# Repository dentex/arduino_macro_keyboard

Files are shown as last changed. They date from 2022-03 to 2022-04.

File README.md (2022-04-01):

# Arduino Macro Keyboard

DIY *Macro Keyboard* using an Arduino Pro Micro, 3D printed parts and some other hardware modules.

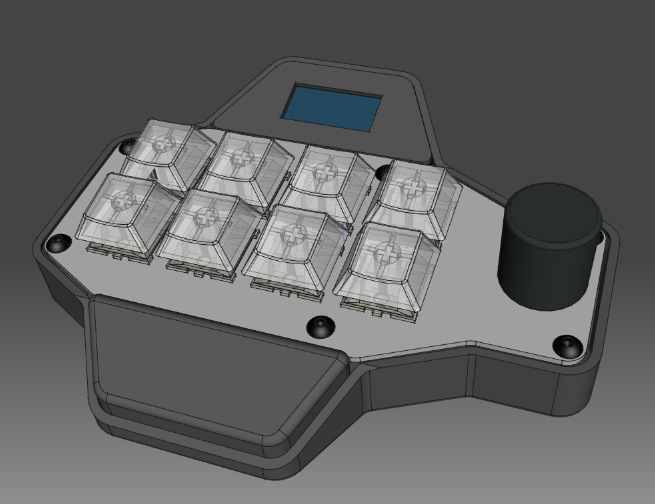
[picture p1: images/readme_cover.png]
cover image


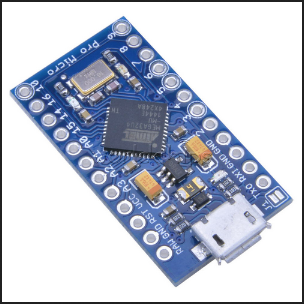
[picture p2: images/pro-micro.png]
pro-micro


## Features

- Arduino Pro Micro as HID device
- 8 configurable keyboard switches and 1 rotary encoder
- Independent profiles for keys and encoder
- Touch sensor to detect interaction
- A ws2812b LED module lights-up the pad upon profile changes and when the touch sensor is touched
- OLED display to show usage info
- Menu Button (placed below the OLED display) with key-test playground

## Arduino sketch

Find it at [./sketch/pro-micro_dentex_macro-keyboard.ino](/sketch/pro-micro_dentex_macro-keyboard.ino).

Libraries used:
- HID-Project
- EEPROM
- Adafruit_NeoPixel
- SSD1306Ascii
- Keypad

## 3D printed parts

Printable STL files are available in the [relative folder](/STL). The [./FreeCAD](/FreeCAD) folder contains the 3D project (the main file to be loaded in FreeCAD is `#_MACRO-KEYBOARD_v12.FCStd`)

## Hardware

- 1 Arduino Pro Micro
- 8 Cherry MX switches (or similar/compatible, i.e.: https://www.aliexpress.com/item/4001111706889.html)
- 8 Keycaps (4xR1 and 4xR2: https://www.aliexpress.com/item/33056163268.html)
- 1 Rotary Encoder (I used a KY_040 module, it should be this one: https://www.aliexpress.com/item/32726570531.html)
- 6 short M3 hexagonal screws
- 6 M3X4.6X4.0 Brass Insert Nuts (i.e.: https://www.aliexpress.com/item/4000688990203.html)
- 1 6x6x5mm tactile mini switch (i.e.: https://www.aliexpress.com/item/1005003536610720.html)
- 1 3mm LED (indicates the encoder's ticking)
- 1 Addressable LED module (i.e.: https://www.aliexpress.com/item/32851699524.html)
- 1 I2C OLED Display Module (i.e.: https://fr.aliexpress.com/item/32584349265.html type 0.96 white)
- 1 TTP223 Capacitive Touch Switch Module(i.e.: https://www.aliexpress.com/item/32869836574.html)

## Wiring

A partial connection diagram is present into the [./images](/images) folder. It covers the keyboard and the rotary encoder. For the other connections, rely on the Arduino sketch and the [arduino pinout](/images/pro-micro-pinout.jpg).

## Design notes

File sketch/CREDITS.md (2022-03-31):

# 1

*T H E   K N O B*
*Media Controller Mk III*

By Frank Lumien: www.lumien.se
Arduino code by: IAmOrion aka James Tanner

Version 2.0

FUNCTIONS
Turn knob left: Volume down
Turn knob right: Volume up
Press knob: Play & Pause (alternating)
Press and turn knob left: Previous track
Press and turn knob right: Next track

Note: You can change all of these functions, see Settings.h for more.

PINOUT, pro-micro to KY-040
D14   to  CLK
D15   to  DT
D16   to  SW
VIN  to  GND // reversed
GND  to  +5V // reversed
Note: The position of these pins may depend on your board and encoder.
If you have already soldered or if The Knob doesn’t behave as expected,
you can adjust the pin settings in Settings.h

# 2

**TinyMultimediaController**
*Multimedia controller using a Digispark*
*(ATtiny85) and a rotary encoder*

Copyright (C) 2018 Costin STROIE <costinstroie@eridu.eu.org>

This program is free software: you can redistribute it and/or modify
it under the terms of the GNU General Public License as published by
the Free Software Foundation, either version 3 of the License, or
(at your option) any later version.

This program is distributed in the hope that it will be useful,
but WITHOUT ANY WARRANTY; without even the implied warranty of
MERCHANTABILITY or FITNESS FOR A PARTICULAR PURPOSE.  See the
GNU General Public License for more details.

You should have received a copy of the GNU General Public License
along with this program.  If not, see <http://www.gnu.org/licenses/>.

# 3

`TODO`

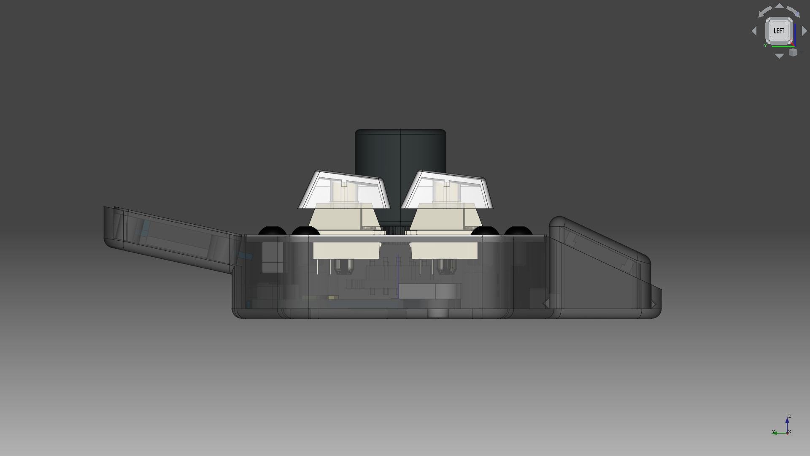
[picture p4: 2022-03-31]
images/o6.png

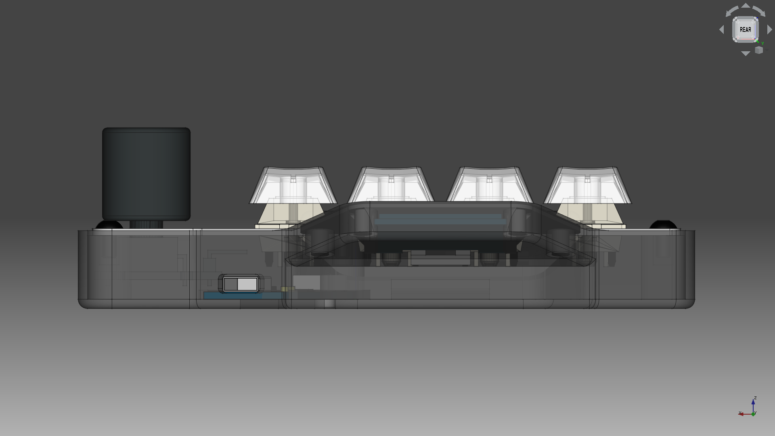
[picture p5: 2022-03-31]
images/o4.png

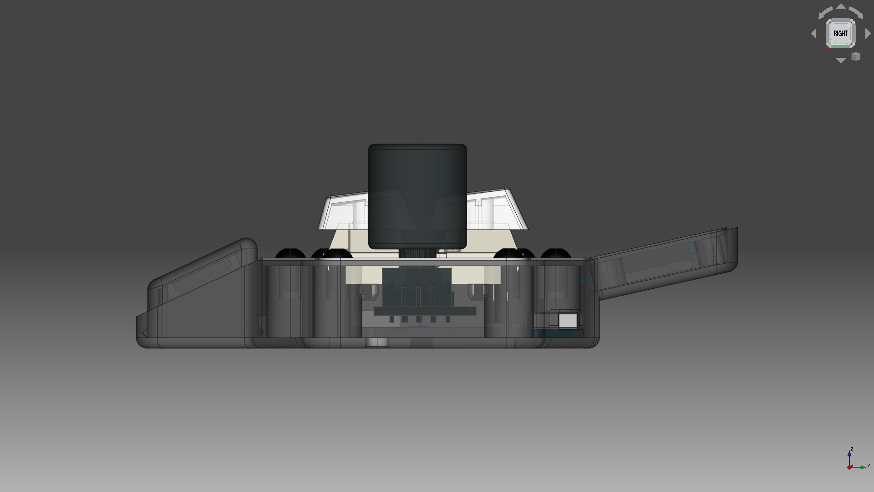
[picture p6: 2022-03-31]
images/o3.png

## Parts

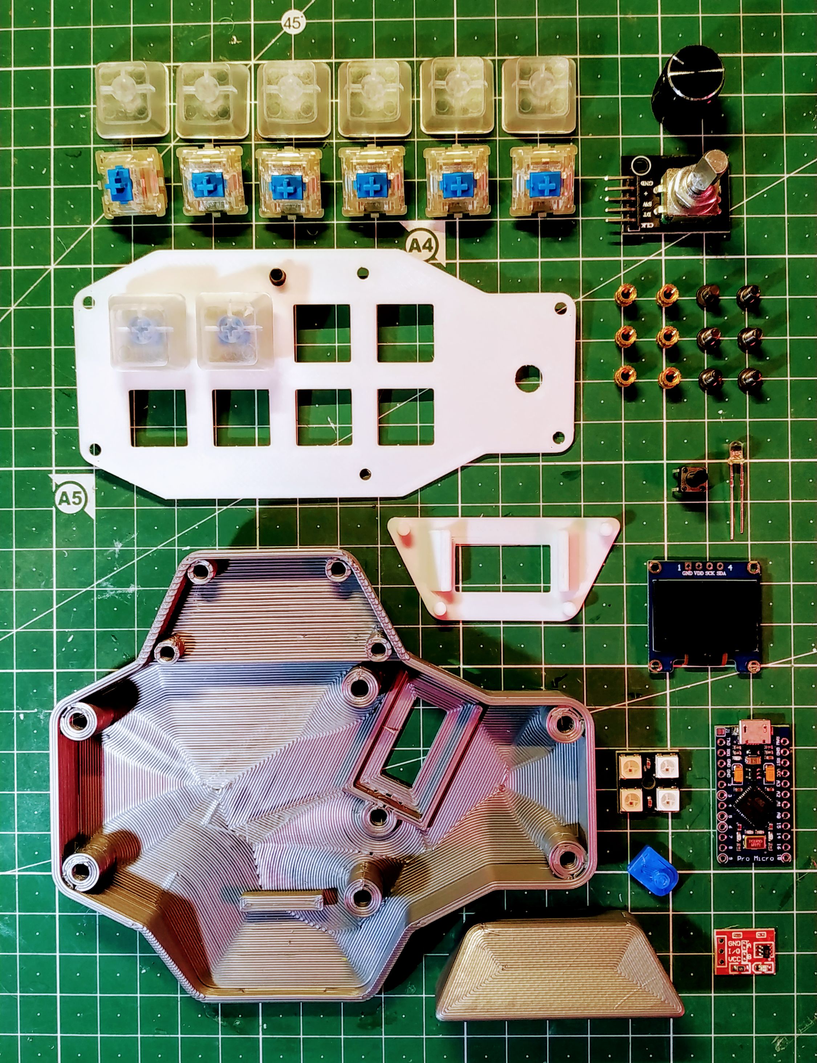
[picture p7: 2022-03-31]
images/IMG_20210107_parts.jpg

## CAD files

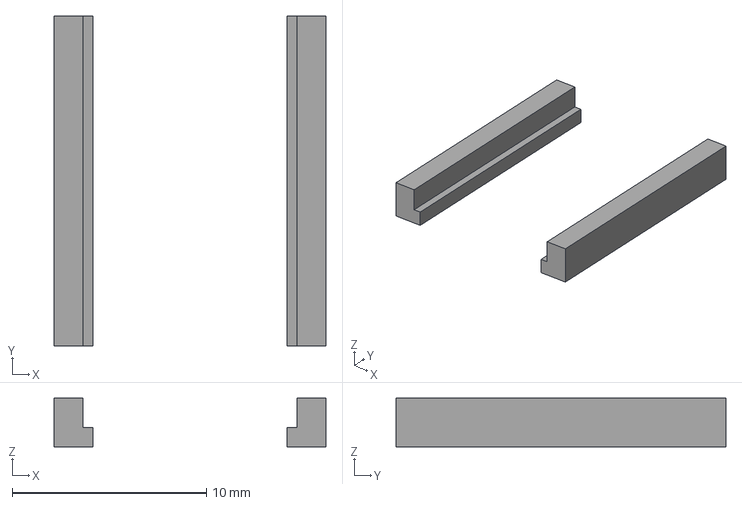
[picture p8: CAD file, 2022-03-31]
FreeCAD/ts-sled.FCStd
14.0 x 17.0 x 2.50 mm
Cut_TS_sled

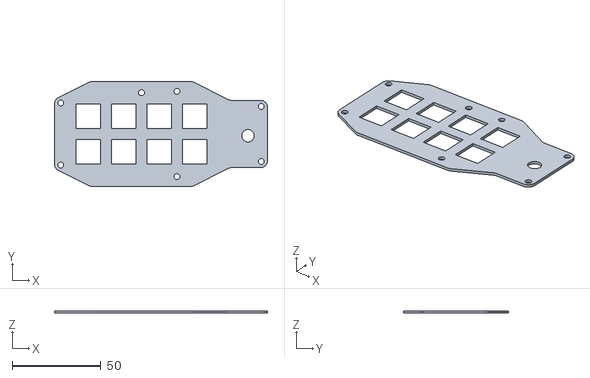
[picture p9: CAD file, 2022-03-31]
STL/cmx_frame_v8.stl
120.0 x 59.0 x 1.40

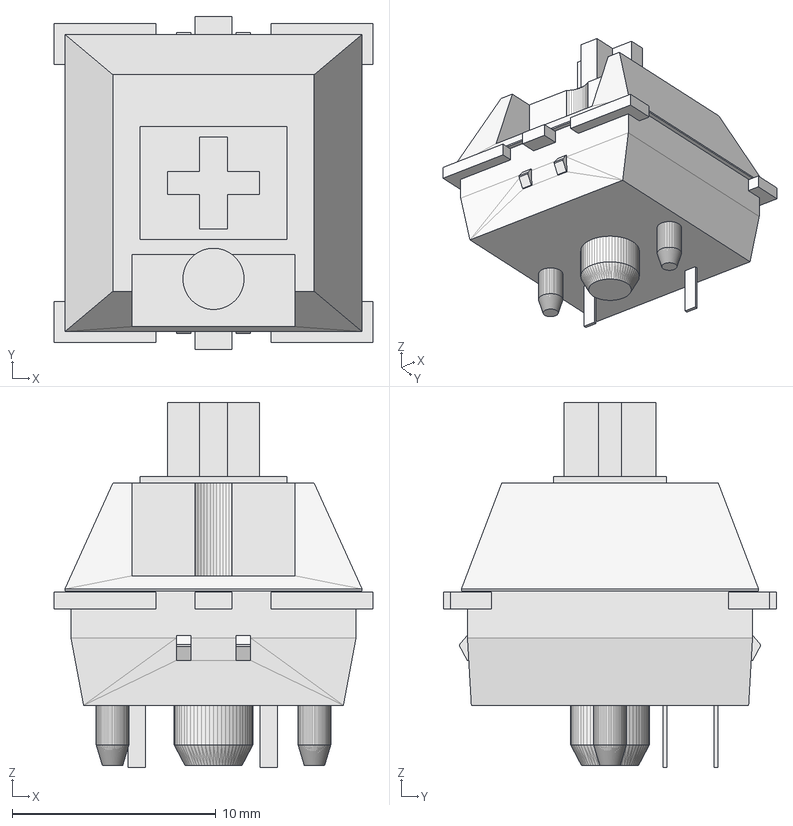
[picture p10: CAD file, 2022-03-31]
FreeCAD/cmx.FCStd
15.6 x 16.3 x 17.9 mm

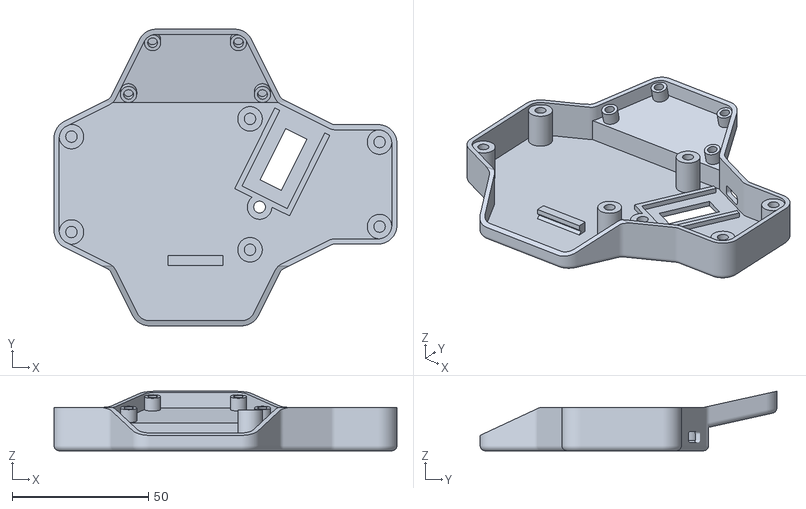
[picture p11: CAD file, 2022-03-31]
STL/base_v10.stl
125.8 x 108.8 x 21.9

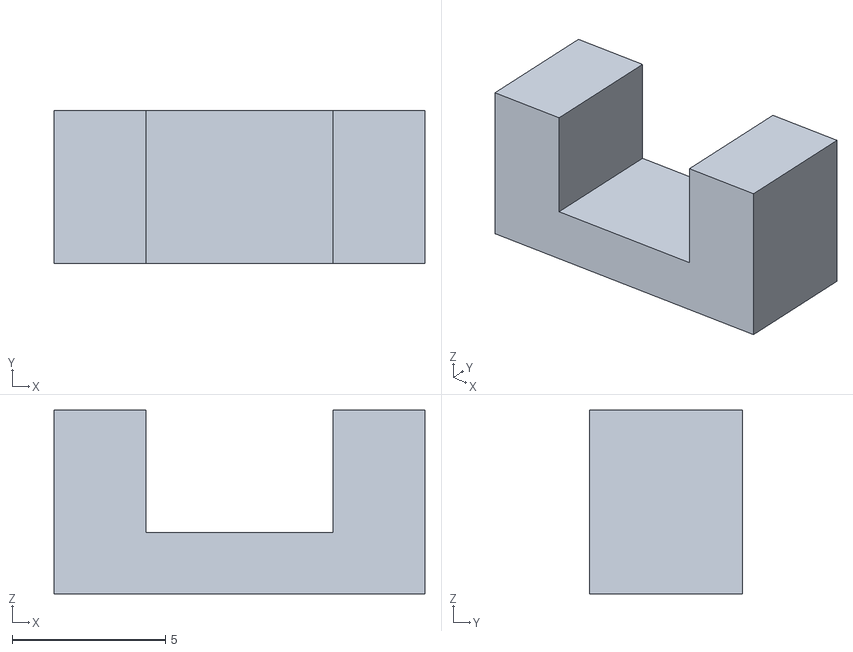
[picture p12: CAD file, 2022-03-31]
STL/mb_supp_v8.stl
12.1 x 5.00 x 6.00

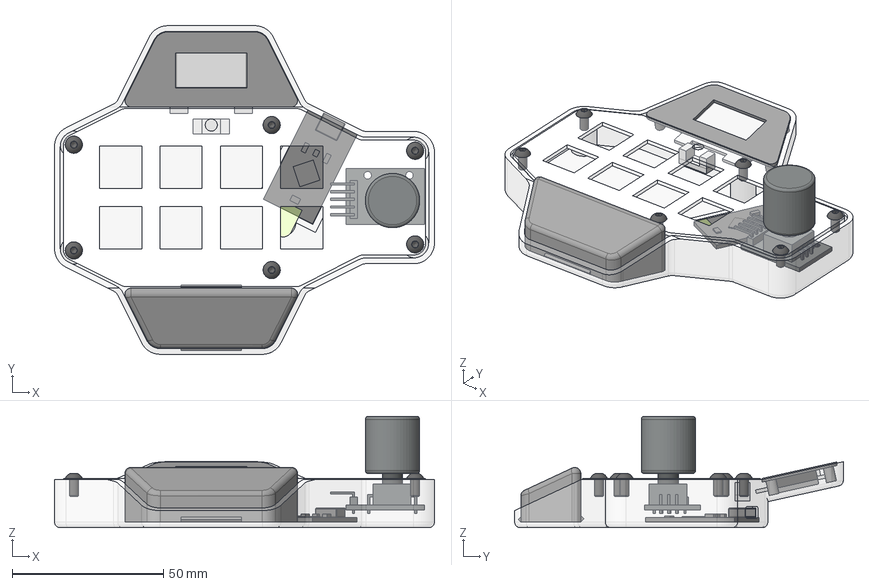
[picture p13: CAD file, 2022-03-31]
FreeCAD/#_MACRO-KEYBOARD_v12.FCStd
125.8 x 108.8 x 36.9 mm
standoffs
Frame_FINAL_[A]
Body_BASE_002
Body_OLED_frame_002
menu_butt_supp
pro-micro_blocker
pro-micro
Body_OLED
encoder+knob
palm-rest_FINAL
M3x6-Screw
M3x6-Screw001
M3x6-Screw002
M3x6-Screw003
M3x6-Screw004
M3x6-Screw005

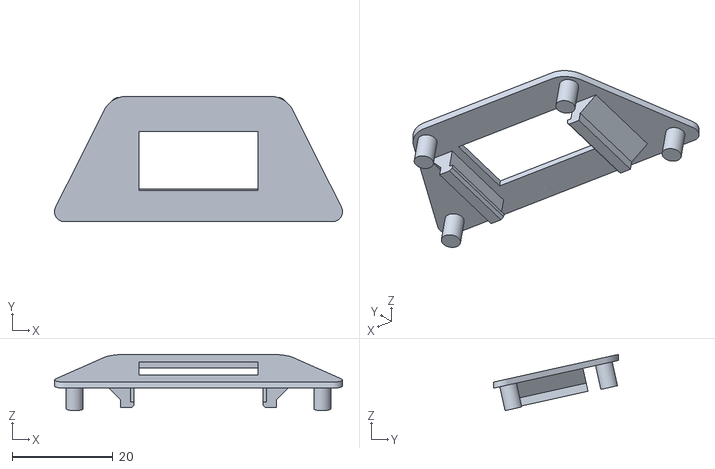
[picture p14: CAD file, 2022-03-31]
STL/OLED_frame_v8.stl
57.1 x 24.8 x 11.2

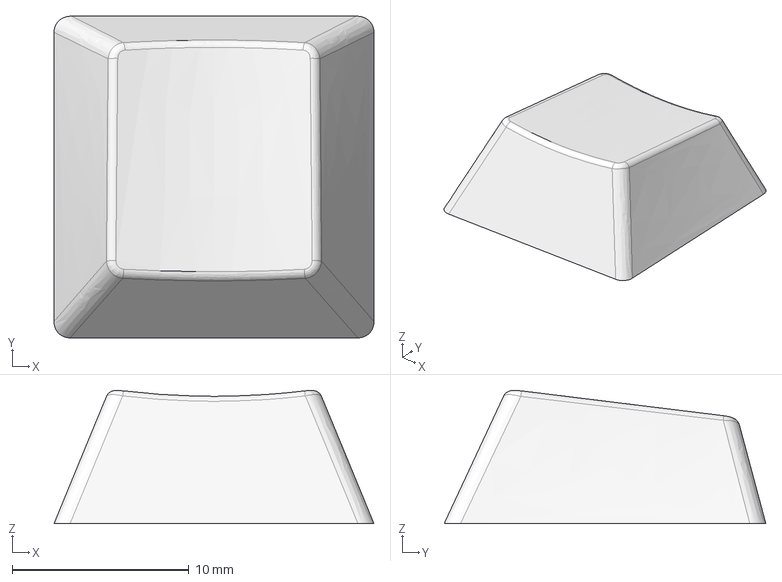
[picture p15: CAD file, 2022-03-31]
FreeCAD/keycap.FCStd
18.1 x 18.2 x 7.54 mm

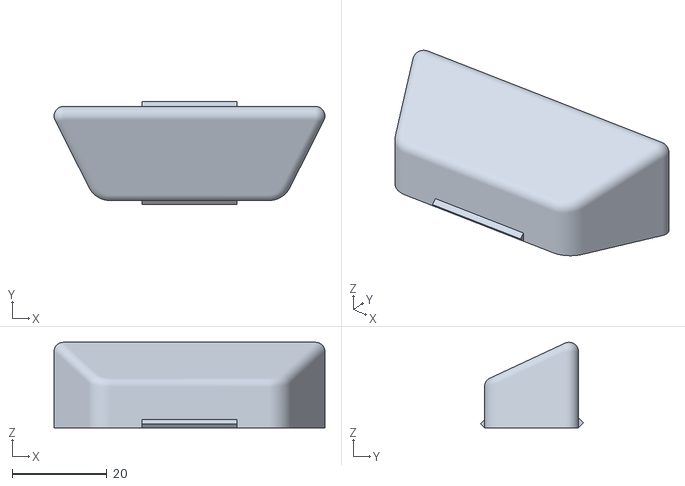
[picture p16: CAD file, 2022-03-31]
STL/palm-rest_v9.stl
57.2 x 21.8 x 18.1

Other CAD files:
FreeCAD/cmx+keycap.FCStd

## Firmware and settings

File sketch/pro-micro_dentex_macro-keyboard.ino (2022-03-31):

/* 
 * Ultimate Macro Keyboard
 * 
 * Copyright (C) 2020 Samuele Rini <samuele.rini76 [AT] gmail.com>
 *
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
 * You should have received a copy of the GNU General Public License
 * along with this program.  If not, see <http://www.gnu.org/licenses/>.
 */

/* 
 * ----------------------------------------
 * Realized adapting and modifing code from 
 * the projects specified under CREDITS.md
 * ----------------------------------------
*/

#include <Arduino.h>

#include "Settings.h"

// #include <EEPROMWearLevel.h>
#include <EEPROM.h>

#include <Adafruit_NeoPixel.h>
Adafruit_NeoPixel strip = Adafruit_NeoPixel(LEDS_NUM, DIN_PIN, NEO_GRB + NEO_KHZ800);

#include "SSD1306Ascii.h"
#include "SSD1306AsciiWire.h"
SSD1306AsciiWire oled;

#include "DeadSimpleMenu.h"
DeadSimpleMenu dsm;

#include <Keypad.h>

byte rowPins[ROWS] = {15, 14};     //connect to the row pinouts of the keypad
byte colPins[COLS] = {4, 5, 6, 7}; //connect to the column pinouts of the keypad

Keypad keypad = Keypad(makeKeymap(keys), rowPins, colPins, ROWS, COLS);

int encButtonState = LOW, lastEncButtonState = LOW;
int menuButtonState = LOW, lastMenuButtonState = LOW;
int touchSensorState = LOW, lastTouchSensorState = LOW;

unsigned long lastDebounceTime = 0, debounceDelay = 50;
int _position = 0, _positionExt = 0;
int8_t _oldState;
bool btnPressed = false, btnReleased = false, pressedRotary = false;

const int8_t encoderStates[] = {
    0, -1, 1, 0,
    1, 0, 0, -1,
    -1, 0, 0, 1,
    0, 1, -1, 0};

//Functions prototypes (due to the optional parameter)
//********************************************************************************
void oledOn(const char *msg, bool isIgnoring = false);
void drawMenu(int page = INITIAL_PAGE);
//void keySend(KeyboardKeycode key, bool useCtrl = false, bool useShift = false);
//********************************************************************************

void colorWipe(uint32_t c, uint8_t wait)
{
    for (uint16_t i = 0; i < strip.numPixels(); i++)
    {
        strip.setPixelColor(i, c);
        strip.show();
        delay(wait);
    }
}

void stripSetColor(uint8_t encP = -1, uint8_t keyP = -1)
{
    uint8_t wait = 100;

    switch (keyP)
    {
    case OLIVE_KP:
        colorWipe(strip.Color(0, 255, 0), wait); // Green
        break;
    case NAV_KP:
        colorWipe(strip.Color(255, 0, 0), wait); // Red
        break;
    default:
        switch (encP)
        {
        case MMEDIA_ENC:
            switch (keyP)
            {
            case APPS_KP:
                colorWipe(strip.Color(0, 0, 255), wait); // Blue
                break;
            case KRITA_KP:
                colorWipe(strip.Color(127, 0, 255), wait); // Purple/Blue
                break;
            }
            break;
        case KRITA_ENC:
            switch (keyP)
            {
            case APPS_KP:
                colorWipe(strip.Color(255, 255, 0), wait); // Yellow
                break;
            case KRITA_KP:
                colorWipe(strip.Color(255, 0, 127), wait); // Purple/Red
                break;
            }
            break;
        default:
            colorWipe(strip.Color(0, 0, 0), wait); // Black
            break;
        }
    }
}

/*
// colors 
colorWipe(strip.Color(255, 0, 0), wait); // Red
colorWipe(strip.Color(0, 255, 0), wait); // Green
colorWipe(strip.Color(0, 0, 255), wait); // Blue
colorWipe(strip.Color(0, 0, 0), wait); // Black 
*/

bool menuMode = false;
bool showcaseMode = false;

int storedEncoderProfile;
int currentEncoderProfile;
int encoderProfile;

int storedKeypadProfile;
int currentKeypadProfile;
int keypadProfile;

void quitMenu()
{
    //Serial.print("\n Exting Menu");
    menuMode = false;
    showcaseMode = false;
    exitMenu();
}

void assignEncoderProfile(int encoderProfile)
{
    //Serial.print("\n Assigning encoder profile ");
    //Serial.print(encoderProfile);
    currentEncoderProfile = encoderProfile;

    EEPROM.update(ENCODER_PROFILE_SETTING, encoderProfile);

    stripSetColor(encoderProfile, currentKeypadProfile);
    stripSetColor();
}

void assignKeypadProfile(int keypadProfile)
{
    //Serial.print("\n Assigning keypad profile ");
    //Serial.print(keypadProfile);
    currentKeypadProfile = keypadProfile;

    EEPROM.update(KEYPAD_PROFILE_SETTING, keypadProfile);

    stripSetColor(currentEncoderProfile, keypadProfile);
    stripSetColor();
}

void setup()
{
    pinMode(encoderPinA, INPUT);
    pinMode(encoderPinB, INPUT);
    pinMode(encoderButton, INPUT);

    digitalWrite(encoderButton, LOW);
    _oldState = 3;

    pinMode(TOUCH_SENSOR, INPUT);

    pinMode(MENU_BUTTON, INPUT);
    digitalWrite(MENU_BUTTON, LOW);

    //Serial.begin(9600 * 2);
    //EEPROMwl.begin(EEPROM_LAYOUT_VERSION, AMOUNT_OF_INDEXES);

    // uncomment to wait for serial connection before continuing
    /* while (!Serial)
    {
        ;
    } */

    storedEncoderProfile = EEPROM.read(ENCODER_PROFILE_SETTING);

    currentEncoderProfile = storedEncoderProfile;
    encoderProfile = storedEncoderProfile;

    storedKeypadProfile = EEPROM.read(KEYPAD_PROFILE_SETTING);

    currentKeypadProfile = storedKeypadProfile;
    keypadProfile = storedKeypadProfile;

    Wire.begin();
    oled.begin(&Adafruit128x64, I2C_ADDRESS);
    oled.setFont(menuFont);

    oledOn(" Macro-Keyboard\n   by Dentex");
    delay(STANDARD_MS);

    oled.clear();

    dsm.attachOled(oled);

    pinMode(TICK_LED, OUTPUT);
    ledOn();
    ledTimeout += ledDelay;

    strip.begin();
    strip.setBrightness(BRIGHTNESS);

    stripSetColor(currentEncoderProfile, currentKeypadProfile);
    stripSetColor();

#ifndef ENCODER_DEBUG
    {
        Consumer.begin();
    }
#endif

    Keyboard.begin();
}

void keySend(KeyboardKeycode key, bool useCtrl = false, bool useShift = false /*, bool useAlt = false */)
{
    if (!menuMode)
    {
        // Turn the LED on
        ledOn();

        // Send the key
        if (useCtrl)
        {
            Keyboard.press(KEY_LEFT_CTRL);
        }
        if (useShift)
        {
            Keyboard.press(KEY_LEFT_SHIFT);
        }
        /* if (useAlt)
        {
            Keyboard.press(KEY_LEFT_ALT);
        } */
        Keyboard.press(key);
        delay(5);
        Keyboard.releaseAll();
    }
}

void consumerSend(ConsumerKeycode key)
{
    ledOn();
    Consumer.write(key);
}

/*
  Turn the LED on and set the timeout
*/
void ledOn()
{
    if (!ledLight)
    {
        ledLight = true;
        digitalWrite(TICK_LED, HIGH);
    }
    ledTimeout = millis() + ledDelay;
}

void oledOn(const char *msg, bool isIgnoring)
{
    const char *oldMsg = "";
    if (!menuMode || isIgnoring)
    {
        if (!oledLight || msg != oldMsg)
        {
            oledLight = true;
            oled.clear();
            oled.setCursor(0, 0);
            oled.println(msg);
            oldMsg = msg;
        }
        oledTimeout = millis() + oledDelay;
    }

    if (showcaseMode)
    {
        oled.setCursor(0, 3);
        oled.println(msg);
        oldMsg = msg;
    }
}

/*
  Check the timeout and turn the LED off

  @param nowMillis cached millis()
*/
void ledOff(unsigned long nowMillis)
{
    if (ledLight and (nowMillis > ledTimeout))
    {
        ledLight = false;
        digitalWrite(TICK_LED, LOW);
    }
}

void oledOff(unsigned long nowMillis)
{
    if (oledLight and (nowMillis > oledTimeout) && !menuMode)
    {
        oledLight = false;
        oled.clear();
    }
}

int getPosition()
{
    return _positionExt;
}

/* void setPosition(int newPosition)
{
    _position = ((newPosition << 2) | (_position & 0x03));
    _positionExt = newPosition;
} */

void tick(void)
{
    int sig1 = digitalRead(encoderPinA);
    int sig2 = digitalRead(encoderPinB);
    int8_t thisState = sig1 | (sig2 << 1);
    if (_oldState != thisState)
    {
        _position += encoderStates[thisState | (_oldState << 2)];
         if ((thisState == 0) || (thisState == 3))
            _positionExt = _position >> 2;
        _oldState = thisState;
    }
}

void exitMenu()
{
    oledOn("EXIT\n Menu");
}

void drawMenu(int page)
{
    oled.clear();
    dsm.menuPage = page;

    switch (page)
    {
    case INITIAL_PAGE: // initial menu page
        dsm.currentLine = 0;
        dsm.maxLinesNum = 3;
        dsm.setLine(0, menuLineEnc + EncProfileNames[currentEncoderProfile]);
        dsm.setLine(1, menuLineKp + KpProfileNames[currentKeypadProfile]);
        dsm.setLine(2, menuLineTest);
        dsm.setLine(3, menuLineBack);
        break;

    case ENC_PROFILE_PAGE: // choose Encoder profile page
        dsm.currentLine = currentEncoderProfile;
        dsm.maxLinesNum = 3;
        dsm.setLine(0, MMEDIA_N);
        dsm.setLine(1, OLIVE_N);
        dsm.setLine(2, KRITA_N);
        dsm.setLine(3, menuLineBack);
        break;

    case KP_PROFILE_PAGE: // choose Keypad profile page
        dsm.currentLine = currentKeypadProfile;
        dsm.maxLinesNum = 3;
        dsm.setLine(0, APPS_N);
        dsm.setLine(1, OLIVE_N);
        dsm.setLine(2, KRITA_N);
        dsm.setLine(3, NAV_N);
        //dsm.setLine(4, menuLineBack);
        break;

    case TEST_KEYS_PAGE: // keypad's keys test page
        //TODO
        dsm.currentLine = 0;
        dsm.maxLinesNum = 0; //just one line [temp]
        dsm.setLine(0, menuLineBack);
        dsm.setLine(1, "");
        dsm.setLine(2, "");
        dsm.setLine(3, "*press any key*");
        break;
    }

    dsm.updateLines();
    delay(100);
    dsm.updateIndicators();
}

void handleEncoderClick(int line)
{
    switch (dsm.menuPage)
    {
    case INITIAL_PAGE: // initial menu page
        switch (line)
        {
        case ENC_PROFILE_PAGE: // Encoder profiles
        case KP_PROFILE_PAGE:  // Keypad profiles
            drawMenu(line);
            break;
        case TEST_KEYS_PAGE: // Test keys
            showcaseMode = true;
            drawMenu(line);
            break;

        case 3: // Go back (EXIT)
            quitMenu();
            break;
        }
        break;

    case ENC_PROFILE_PAGE: // choose Encoder profile menu page
        switch (line)
        {
        case MMEDIA_ENC:
        case OLIVE_ENC:
        case KRITA_ENC:
            assignEncoderProfile(line);
            drawMenu();
            break;
        case 3:
            drawMenu();
            break;
        }
        break;

    case KP_PROFILE_PAGE: // choose Keypad profile menu page
        switch (line)
        {
        case APPS_KP:
        case OLIVE_KP:
        case KRITA_KP:
        case NAV_KP:
            assignKeypadProfile(line);
            drawMenu();
            break;
        /* case 3:
            drawMenu();
            break;*/
        } 
        break;

    case TEST_KEYS_PAGE: // Test keys menu page
        showcaseMode = false;
        drawMenu(INITIAL_PAGE);
        break;
    }
}

void enterMenu()
{
    //Serial.println("Entering menu");
    oledOn("ENTER\n Menu", true);
    delay(STANDARD_MS);

    drawMenu();
}

void watchButtons(unsigned long nowMillis)
{
    // read the state of the switch into a local variable:
    int menuReading = digitalRead(MENU_BUTTON);
    int touchSensorReading = digitalRead(TOUCH_SENSOR);

    // check to see if you just pressed the button
    // (i.e. the input went from LOW to HIGH), and you've waited long enough
    // since the last press to ignore any noise:

    // If the switch changed, due to noise or pressing:
    if ((menuReading != lastMenuButtonState) || (touchSensorReading != lastTouchSensorState))
    {
        // reset the debouncing timer
        lastDebounceTime = millis();
    }

    if ((millis() - lastDebounceTime) > debounceDelay)
    {
        // whatever the menu button reading is at, it's been there for longer than the debounce
        // delay, so take it as the actual current state:

        // if the button state has changed:
        if (menuReading != menuButtonState)
        {
            menuButtonState = menuReading;

            // only toggle the LED if the new button state is HIGH
            if (menuButtonState == HIGH)
            {
                // start button press code
                ledOn();
                menuMode = !menuMode;
                // end button press code

                if (menuMode)
                {
                    enterMenu();
                }
                else
                {
                    if (showcaseMode)
                    {
                        showcaseMode = false;
                    }

                    exitMenu();
                }

                // delay before considering a 'long-press'
                //delay(STANDARD_MS);

                /* while (digitalRead(MENU_BUTTON) == HIGH)
                {
                    //this section runs every 250ms
                    //while keeping MENU_BUTTON pressed

                    // delay between subsequent keys during 'long-press' phase
                    delay(250);
                } */
            }
        }

        // if the touch sensor state has changed:
        if (touchSensorReading != touchSensorState)
        {
            touchSensorState = touchSensorReading;

            if (touchSensorState == HIGH)
            {
                //ledOn();
                //delay(STANDARD_MS);
                stripSetColor(currentEncoderProfile, currentKeypadProfile);
            }
            else
            {
                stripSetColor();
            }
        }
    }
    ledOff(nowMillis);

    lastMenuButtonState = menuReading;
    lastTouchSensorState = touchSensorReading;
}

void normalOps(bool isMenuMode)
{
    static int pos = 0;
    tick();
    int newPos = getPosition();
    if (pos != newPos)
    {
        if (newPos < pos)
        {
            if (isMenuMode)
            {
                dsm.menuUp();
            }
            else
            {
                if (!btnPressed)
                {
#ifndef ENCODER_DEBUG
                    {
                        switch (currentEncoderProfile)
                        {
                        case MMEDIA_ENC:
                            consumerSend(LEFT_ACTION_MM);
                            break;
                        case OLIVE_ENC:
                            keySend(LEFT_ACTION_O);
                            break;
                        case KRITA_ENC:
                            keySend(LEFT_ACTION_K, true);
                            break;
                        default:
                            // statements
                            break;
                        }
                    }
#else
                    {
                        keySend(LEFT_ACTION_D, false, true); // SHIFT for uppercase
                    }
#endif
                }
                else
                {
                    pressedRotary = true;
#ifndef ENCODER_DEBUG
                    {
                        switch (currentEncoderProfile)
                        {
                        case MMEDIA_ENC:
                            consumerSend(LEFT_ACTION_MODE1_MM);
                            break;
                        case OLIVE_ENC:
                            keySend(LEFT_ACTION_MODE1_O);
                            break;
                        case KRITA_ENC:
                            keySend(LEFT_ACTION_MODE1_K, true);
                            break;
                        default:
                            // statements
                            break;
                        }
                    }
#else
                    {
                        keySend(LEFT_ACTION_MODE1_D);
                    }
#endif
                }
            }
        }
        else if (newPos > pos)
        {
            if (isMenuMode)
            {
                dsm.menuDown();
            }
            else
            {
                if (!btnPressed)
                {
#ifndef ENCODER_DEBUG
                    {
                        switch (currentEncoderProfile)
                        {
                        case MMEDIA_ENC:
                            consumerSend(RIGHT_ACTION_MM);
                            break;
                        case OLIVE_ENC:
                            keySend(RIGHT_ACTION_O);
                            break;
                        case KRITA_ENC:
                            keySend(RIGHT_ACTION_K, true);
                            break;
                        default:
                            // statements
                            break;
                        }
                    }
#else
                    {
                        keySend(RIGHT_ACTION_D, false, true); // SHIFT for uppercase
                    }
#endif
                }
                else
                {
                    pressedRotary = true;
#ifndef ENCODER_DEBUG
                    {
                        switch (currentEncoderProfile)
                        {
                        case MMEDIA_ENC:
                            consumerSend(RIGHT_ACTION_MODE1_MM);
                            break;
                        case OLIVE_ENC:
                            keySend(RIGHT_ACTION_MODE1_O);
                            break;
                        case KRITA_ENC:
                            keySend(RIGHT_ACTION_MODE1_K, true);
                            break;
                        default:
                            // statements
                            break;
                        }
                    }
#else
                    {
                        keySend(RIGHT_ACTION_MODE1_D);
                    }
#endif
                }
            }
        }
        pos = newPos;
    }

    int encReading = digitalRead(encoderButton);
    if (encReading != lastEncButtonState)
    {
        lastDebounceTime = millis();
    }
    if ((millis() - lastDebounceTime) > debounceDelay)
    {
        if (encReading != encButtonState)
        {
            encButtonState = encReading;
            if (encButtonState == HIGH)
            {
                btnPressed = true;
            }
            else if (encButtonState == LOW)
            {
                btnReleased = true;
            }
        }
    }
    lastEncButtonState = encReading;

    if (btnPressed == true && btnReleased == true && pressedRotary == false)
    {
        if (isMenuMode)
        {
            handleEncoderClick(dsm.currentLine);
        }
        else
        {
#ifndef ENCODER_DEBUG
            {
                switch (currentEncoderProfile)
                {
                case MMEDIA_ENC:
                    consumerSend(BUTTON_ACTION_MM);
                    break;
                case OLIVE_ENC:
                    keySend(BUTTON_ACTION_O);
                    break;
                case KRITA_ENC:
                    keySend(BUTTON_ACTION_K, true);
                    break;
                default:
                    // statements
                    break;
                }
            }
#else
            {
                keySend(BUTTON_ACTION_D, false, true); // SHIFT for uppercase
            }
#endif
        }

        btnPressed = false;
        btnReleased = false;
    }
    else if (btnPressed == true && btnReleased == true && pressedRotary == true)
    {
        //RELEASED_AFTER_HELD_ROTATION
        btnPressed = false;
        btnReleased = false;
        pressedRotary = false;
    }
}
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
void loop()
{
    // Keep the time
    unsigned long nowMillis = millis();

    watchButtons(nowMillis);

    watchKeypad();

    normalOps(menuMode);

    // Turn LED and OLED off, if timed out
    ledOff(nowMillis);
    oledOff(nowMillis);
}

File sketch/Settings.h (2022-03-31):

#include <HID-Project.h>
#include <HID-Settings.h>

// Pin settings
#define encoderPinA PIN_A1 // DT -- (volume UP)
#define encoderPinB PIN_A0 // CLK - (volume DOWN)
#define encoderButton PIN_A2
#define TICK_LED 16 //8
#define WS2812_LED 10
#define MENU_BUTTON 8  //9
#define TOUCH_SENSOR 9 //16

// Tick LED stuff
bool ledLight = false;           // Status flag for the LED (on or off)
unsigned long ledTimeout = 0UL;  // The time when the LED will turn off
unsigned long ledDelay = 20UL;   // Time delay after which the LED turns off
unsigned long STANDARD_MS = 500; // A generic delay

// Tick OLED screen message stuff
bool oledLight = false;          // Status flag for the OLED screen (on or off)
unsigned long oledTimeout = 0UL; // The time when the OLED screen will turn off
unsigned long oledDelay = 750UL; // Time delay after which the OLED screen turns off

// WS2812 LEDs stuff
#define DIN_PIN 10
#define LEDS_NUM 3
#define BRIGHTNESS 64

//Keypad stuff
#define ROWS 2
#define COLS 4

char keys[ROWS][COLS] = {
    {'0', '1', '2', '3'},
    {'4', '5', '6', '7'}};

// EEPROMwl setup
// #define EEPROM_LAYOUT_VERSION 0
// #define AMOUNT_OF_INDEXES 1
#define ENCODER_PROFILE_SETTING 10
#define KEYPAD_PROFILE_SETTING 11

// Menu and profiles
String menuLineEnc = "Encoder: ";
String menuLineKp = "Keypad: ";
String menuLineTest = "Test Keys";
String menuLineBack = "<=";

enum MenuPages
{
  INITIAL_PAGE = -1,
  ENC_PROFILE_PAGE = 0,
  KP_PROFILE_PAGE = 1,
  TEST_KEYS_PAGE = 2
};

enum EncProfilesNum
{
  MMEDIA_ENC = 0,
  OLIVE_ENC = 1,
  KRITA_ENC = 2
};

enum KpProfilesNum
{
  APPS_KP = 0,
  OLIVE_KP = 1,
  KRITA_KP = 2,
  NAV_KP = 3
};

String MMEDIA_N = "MMedia";
String OLIVE_N = "Olive";
String KRITA_N = "Krita";
String APPS_N = "Apps";
String NAV_N =  "Nav";

String EncProfileNames[] = { MMEDIA_N, OLIVE_N, KRITA_N };
String KpProfileNames[] = { APPS_N, OLIVE_N, KRITA_N, NAV_N };


// ENCODER profiles:
//========================================================================================
// MultiMedia
#define LEFT_ACTION_MM MEDIA_VOL_DOWN
#define LEFT_ACTION_MODE1_MM MEDIA_PREV

#define RIGHT_ACTION_MM MEDIA_VOL_UP
#define RIGHT_ACTION_MODE1_MM MEDIA_NEXT

#define BUTTON_ACTION_MM MEDIA_PLAY_PAUSE

// Olive
#define LEFT_ACTION_O KEY_LEFT_ARROW
#define LEFT_ACTION_MODE1_O KEY_UP_ARROW

#define RIGHT_ACTION_O KEY_RIGHT_ARROW
#define RIGHT_ACTION_MODE1_O KEY_DOWN_ARROW

#define BUTTON_ACTION_O KEY_SPACE

// Krita
// (Zoom +/- and reset
//  increase/decrease brush via CTRL+8 and CTRL+9 custom shortcuts)
#define ctrlKey KEY_LEFT_CTRL;

#define LEFT_ACTION_K KEY_SLASH        // '-' is '/' on the US keyboard
#define LEFT_ACTION_MODE1_K KEY_8

#define RIGHT_ACTION_K KEY_RIGHT_BRACE  // '+' is ']' on the US keyboard
#define RIGHT_ACTION_MODE1_K KEY_9

#define BUTTON_ACTION_K KEY_0

// DEBUG
#define LEFT_ACTION_D KEY_L
#define LEFT_ACTION_MODE1_D KEY_0

#define RIGHT_ACTION_D KEY_R
#define RIGHT_ACTION_MODE1_D KEY_1

#define BUTTON_ACTION_D KEY_B
//========================================================================================
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
